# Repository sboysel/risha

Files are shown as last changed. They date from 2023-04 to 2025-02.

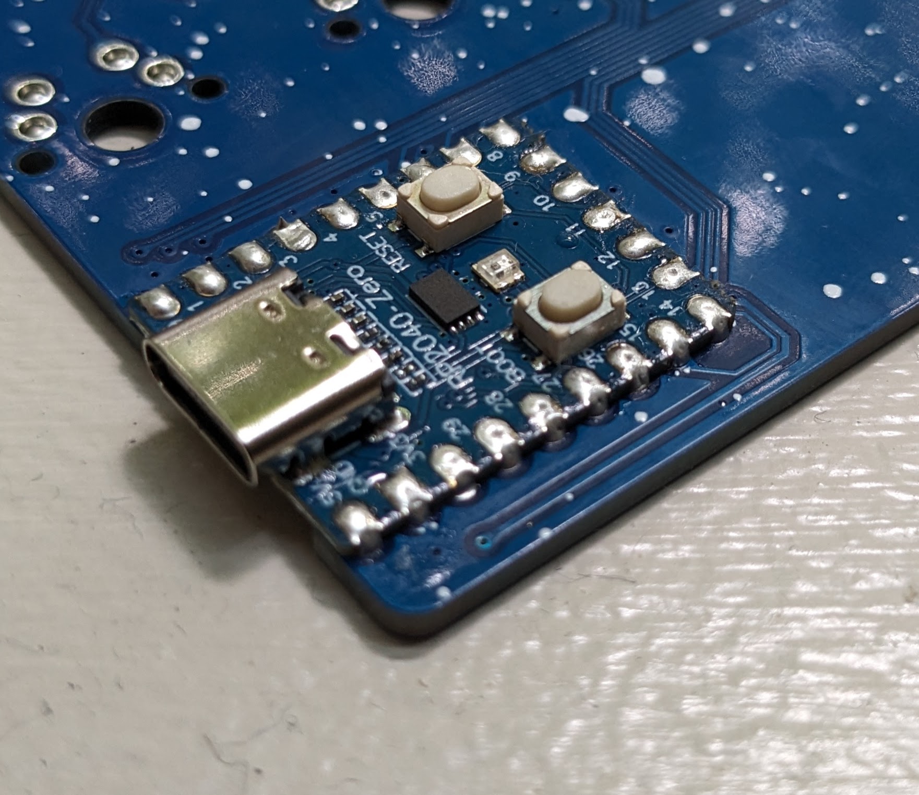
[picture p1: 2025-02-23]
img/rp2040zero-soldered.jpg

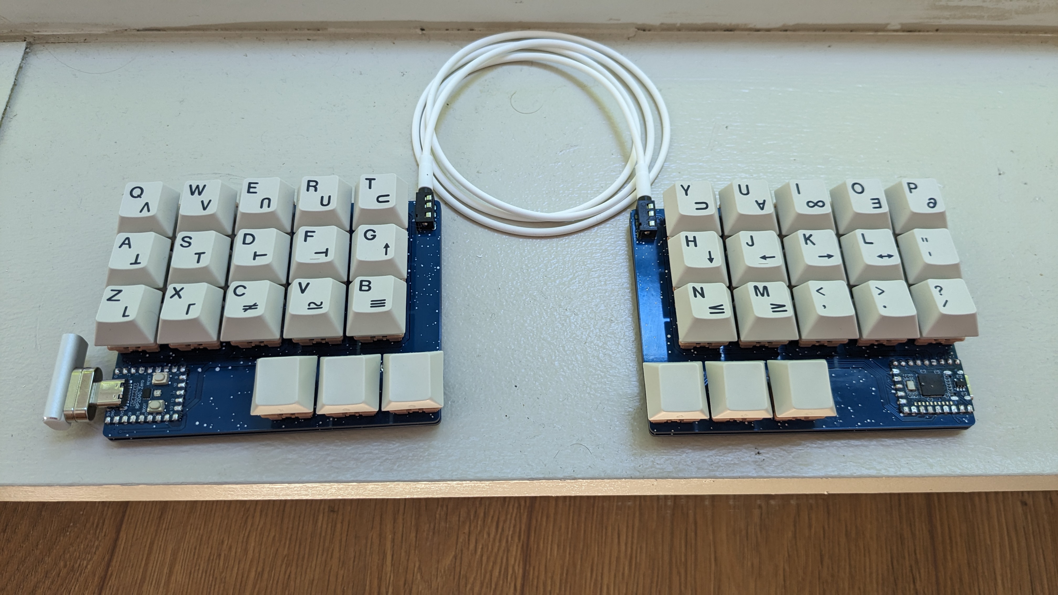
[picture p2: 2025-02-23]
img/full-build.jpg

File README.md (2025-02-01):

# Risha

Risha is an ultra-compact, wired split ortholinear keyboard featuring:

- **36 keys**
- **Diodeless, reversible PCB** (under 102mm x 102mm)
- **Waveshare RP2040-Zero** (cutout for flush mounting)
- **Rear-facing TRRS connection**

This design prioritizes affordability, simplicity, and ease of assembly. With a total cost of around **$40 AUD**, it's an excellent choice for a budget-friendly custom keyboard.

## Features

- **Fully split layout** with only 36 keys
- **No diodes required** for a simpler build process
- **Reversible PCB** (same PCB can be used for both halves)
- **Compact design** for travel and portability
- **RP2040-Zero powered**, enabling powerful firmware support with KMK
- **TRRS interconnection** between the halves

## Getting Started

To build your own Risha, check out the following guides:

- [Buying List](docs/buying_list.md) – Everything you need to order.
- [Build Instructions](docs/build_instructions.md) – Step-by-step assembly guide.
- [Flashing Guide](docs/flashing.md) – Installing KMK firmware.

## License
This project is open-source and freely available for personal and commercial use. Contributions are welcome!

---

### Additional Resources
- [KMK Firmware](https://github.com/KMKfw/kmk_firmware) – The firmware used for Risha
- [RP2040-Zero Docs](https://www.waveshare.com/wiki/RP2040-Zero) – Official documentation for the microcontroller

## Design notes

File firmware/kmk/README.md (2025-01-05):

# clyde kmk firmware

1. copy [CircuitPython](https://circuitpython.org/board/waveshare_rp2040_zero/) to RP2040 Zero
    ```sh
    wget https://downloads.circuitpython.org/bin/waveshare_rp2040_zero/en_US/adafruit-circuitpython-waveshare_rp2040_zero-en_US-8.2.4.uf2
    cp adafruit-circuitpython-waveshare_rp2040_zero-en_US-8.2.4.uf2 /run/media/sam/RPI-RP2/
    ```
2. Rename RP2040 Zeroes to end in `L` and `R`
    ```
    sudo umount /dev/sdb1
    sudo fatlabel /dev/sdb1 RISHAL
    ```
    Repeat for `RISHAR`
3. Copy `kmk_firmware/kmk` directory to each RP2040 Zero
    ```sh
    rm /run/media/sam/RISHAL/code.py
    cp -avr ~/repos/kmk_firmware/kmk /run/media/sam/RISHAL
    cp ~/repos/risha/firmware/kmk/kb.py /run/media/sam/RISHAL 
    cp ~/repos/risha/firmware/kmk/main.py /run/media/sam/RISHAL 
    ```
    Repeat for `RISHAR`
4. Copy board firmware to each RP2040 Zero. Use Piantor firmware as a starting point
    - https://raw.githubusercontent.com/cairnm/kmk_firmware/piantor/boards/beekeeb/piantor/kb.py
    - https://raw.githubusercontent.com/cairnm/kmk_firmware/piantor/boards/beekeeb/piantor/main.py 

## docs

- https://circuitpython.org/board/weact_studio_pico/
- http://kmkfw.io/docs/split_keyboards/

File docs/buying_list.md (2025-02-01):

# Buying List

Risha is an incredibly affordable custom keyboard, costing approximately **\$40 AUD** to build. Below are the essential and optional components required.

## Essential Parts

- **2 x Waveshare RP2040-Zero**
- **2 x TRRS jacks**
- **36 x Cherry MX-compatible switches**
- **A standard Cherry keycap set**

## Optional Parts

- **Rubber bumpers** for added grip and stability
- **Braided USB-C cable** for durability and aesthetics

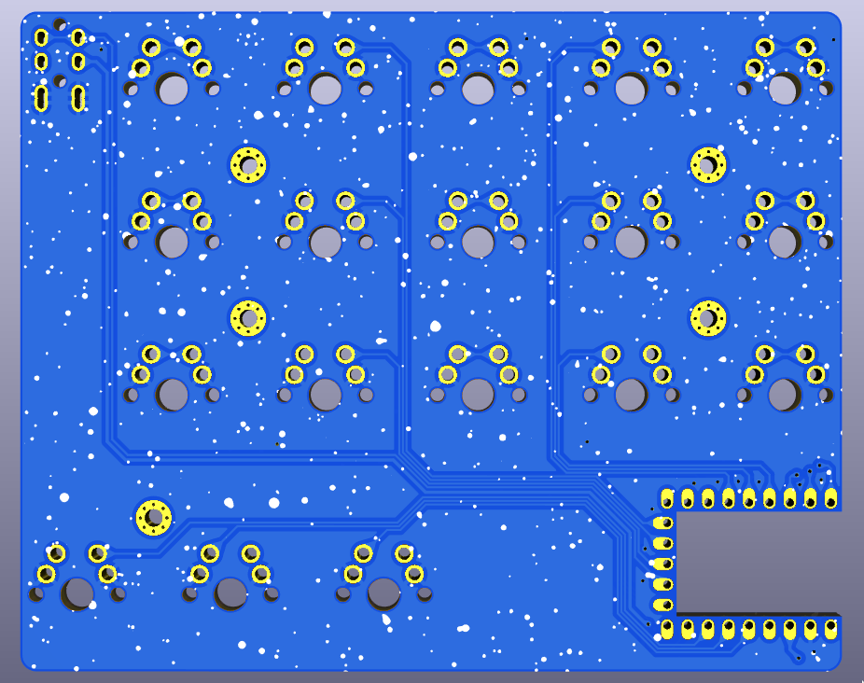
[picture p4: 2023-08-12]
img/risha-v0_3_0.png

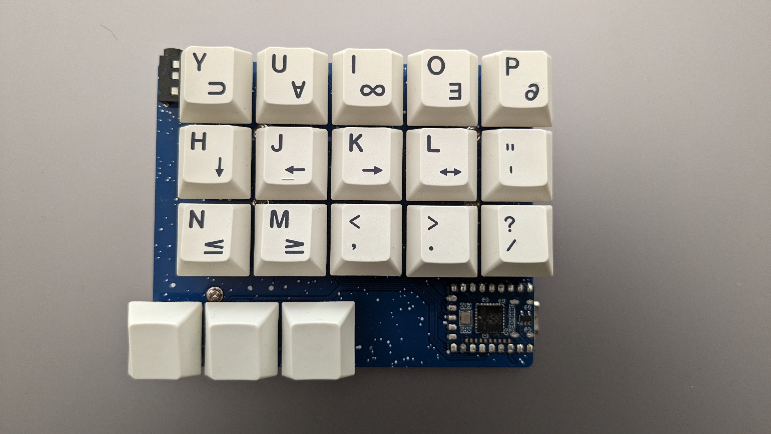
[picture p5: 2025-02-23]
img/rhs.jpg

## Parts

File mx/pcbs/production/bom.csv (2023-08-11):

Designator | Footprint | Quantity | Value | LCSC Part #
 | rp2040_zero_tht_pads | 1
S1, S10, S11, S12, S13, S14, S15, S16, S17, S18, S2, S3, S4, S5, S6, S7, S8, S9 | MX | 18
TRRS1 | TRRS-PJ-320A-dual | 1 | TRRS-PJ-320A-dual
_4, _5, _6 | MountingHole_2.2mm_M2_Pad_Via | 3

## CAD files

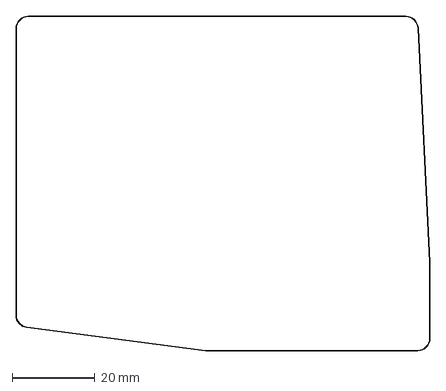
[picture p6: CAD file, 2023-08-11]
choc/outlines/risha-choc-bottom-plate.dxf
100.0 x 80.8 mm

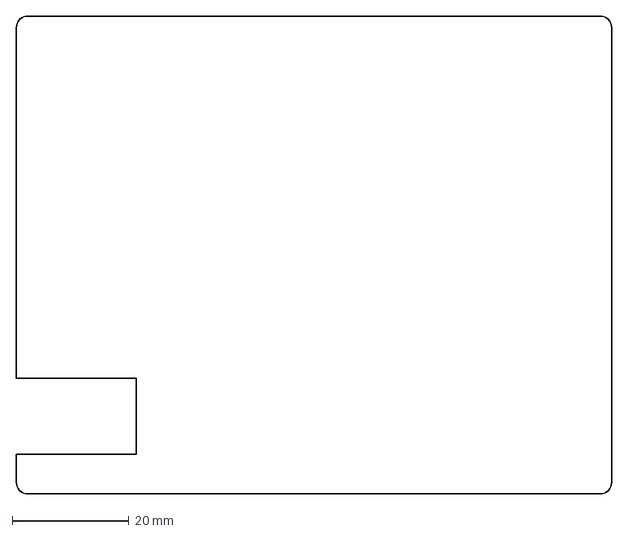
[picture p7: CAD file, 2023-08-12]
ergogen/outlines/risha.dxf
102.0 x 81.9 mm

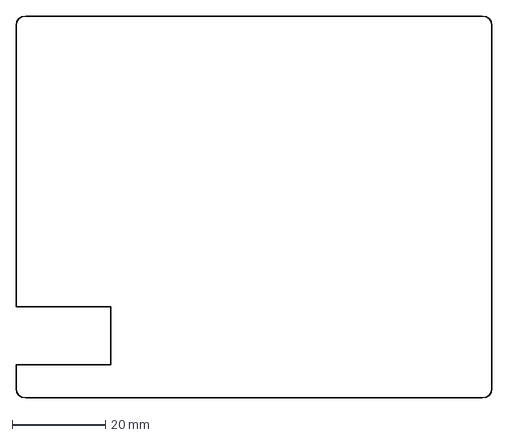
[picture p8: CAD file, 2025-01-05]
ergogen/output/outlines/risha.dxf
102.0 x 81.9 mm

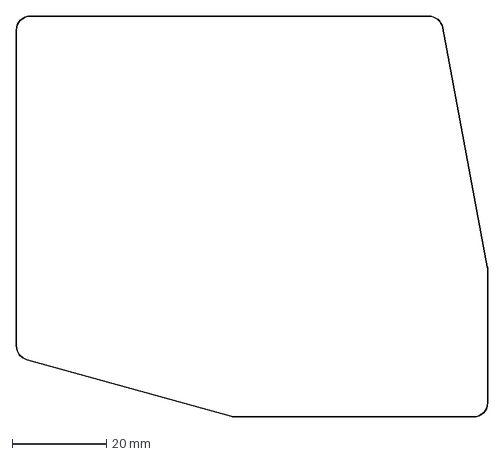
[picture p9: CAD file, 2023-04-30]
output/outlines/mosaic_bottom_plate.dxf
100.0 x 85.0 mm

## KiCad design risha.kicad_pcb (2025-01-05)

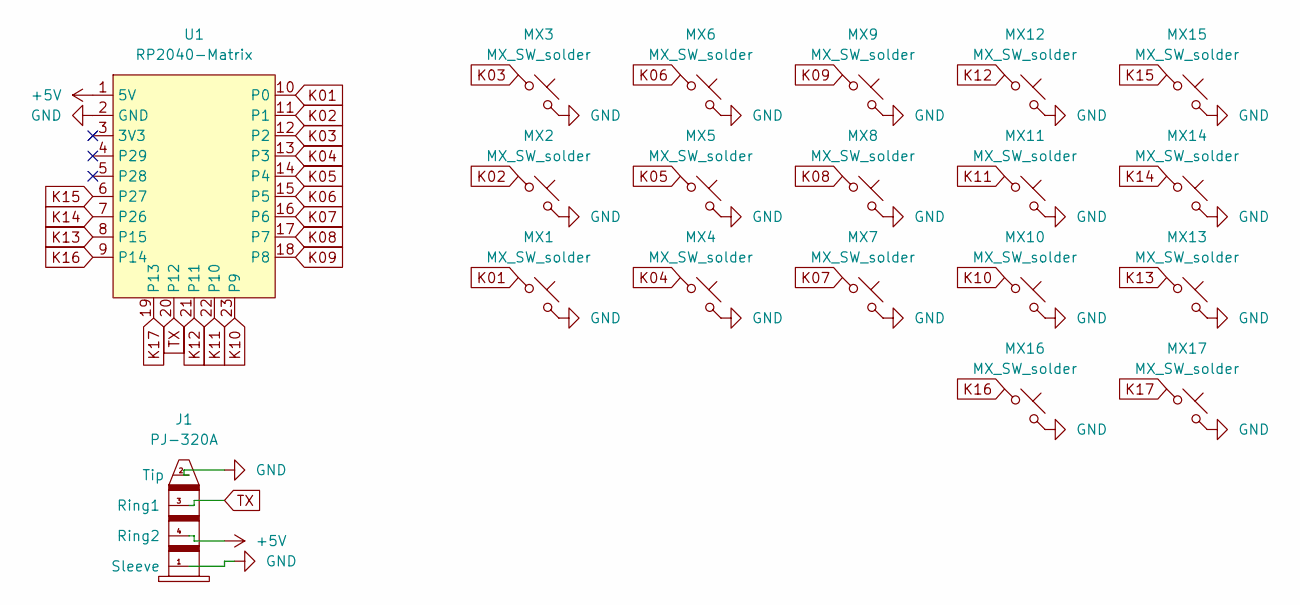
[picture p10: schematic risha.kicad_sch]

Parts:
J1: PJ-320A; PJ-320A_Reversible
MX1, MX2, MX3, MX4, MX5, MX6, MX7, MX8, MX9, MX10, MX11, MX12, MX13, MX14, MX15, MX16, MX17: MX_SW_solder; SW_MX_Reversible_1u
U1: RP2040-Matrix; RP2040-Matrix_AH

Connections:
+5V: J1.4 (Ring2), U1.1 (5V)
GND: J1.1 (Sleeve), J1.2 (Tip), MX1.2, MX2.2, MX3.2, MX4.2, MX5.2, MX6.2, MX7.2, MX8.2, MX9.2, MX10.2, MX11.2, MX12.2, MX13.2, MX14.2, MX15.2, MX16.2, MX17.2, U1.2 (GND)
K01: MX1.1, U1.10 (P0)
K02: MX2.1, U1.11 (P1)
K03: MX3.1, U1.12 (P2)
K04: MX4.1, U1.13 (P3)
K05: MX5.1, U1.14 (P4)
K06: MX6.1, U1.15 (P5)
K07: MX7.1, U1.16 (P6)
K08: MX8.1, U1.17 (P7)
K09: MX9.1, U1.18 (P8)
K10: MX10.1, U1.23 (P9)
K11: MX11.1, U1.22 (P10)
K12: MX12.1, U1.21 (P11)
K13: MX13.1, U1.8 (P15)
K14: MX14.1, U1.7 (P26)
K15: MX15.1, U1.6 (P27)
K16: MX16.1, U1.9 (P14)
K17: MX17.1, U1.19 (P13)
TX: J1.3 (Ring1), U1.20 (P12)

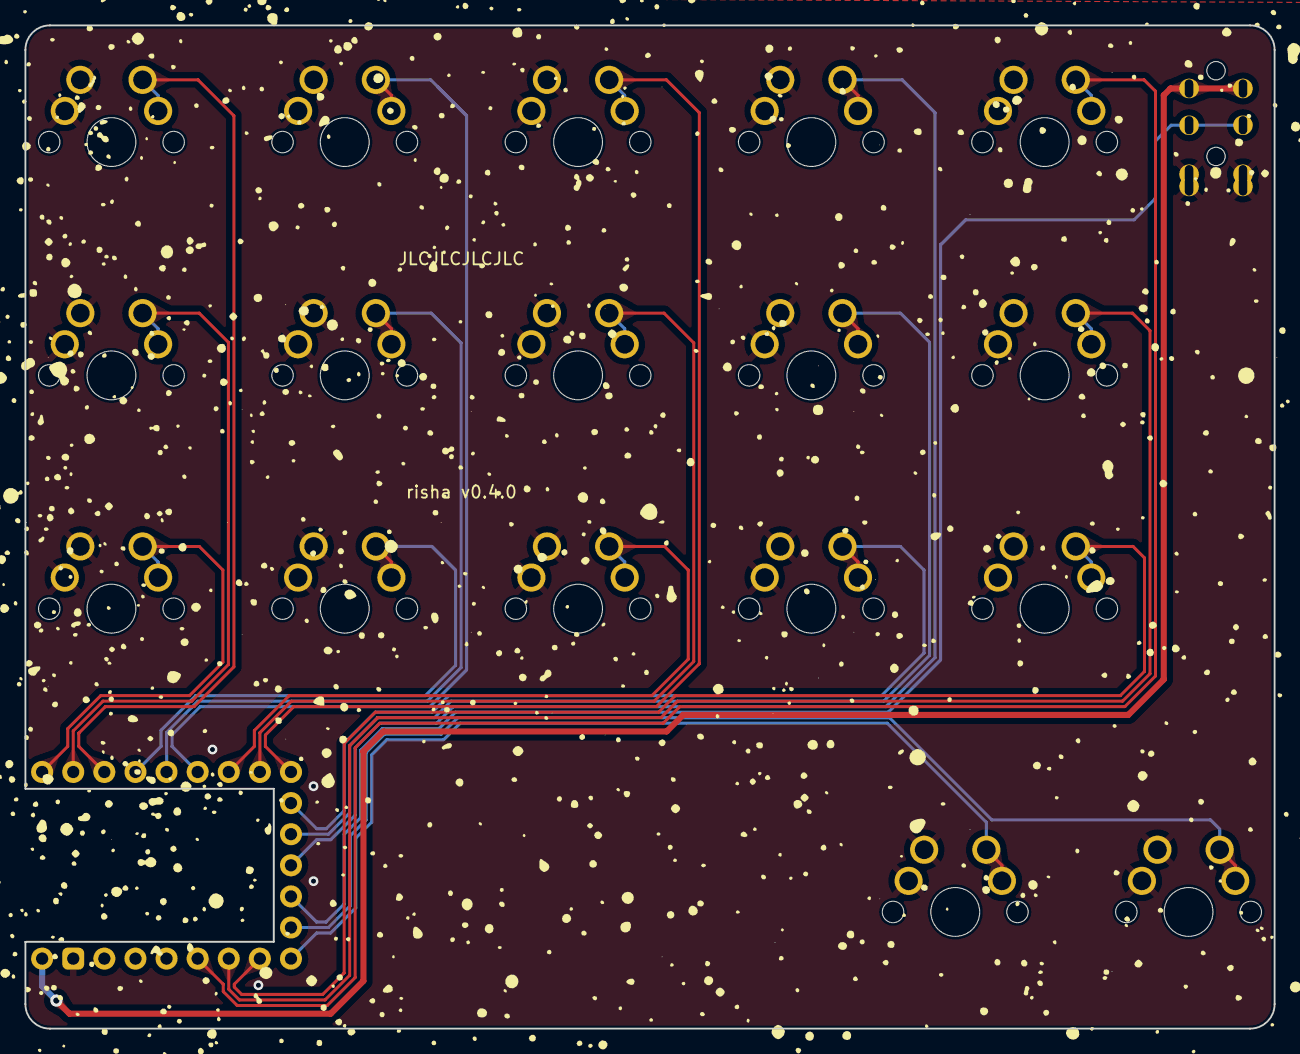
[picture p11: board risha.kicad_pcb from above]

Board: 2 copper layers, 102.0 x 81.9 mm, 19 parts (0 on the bottom side), 20 nets.

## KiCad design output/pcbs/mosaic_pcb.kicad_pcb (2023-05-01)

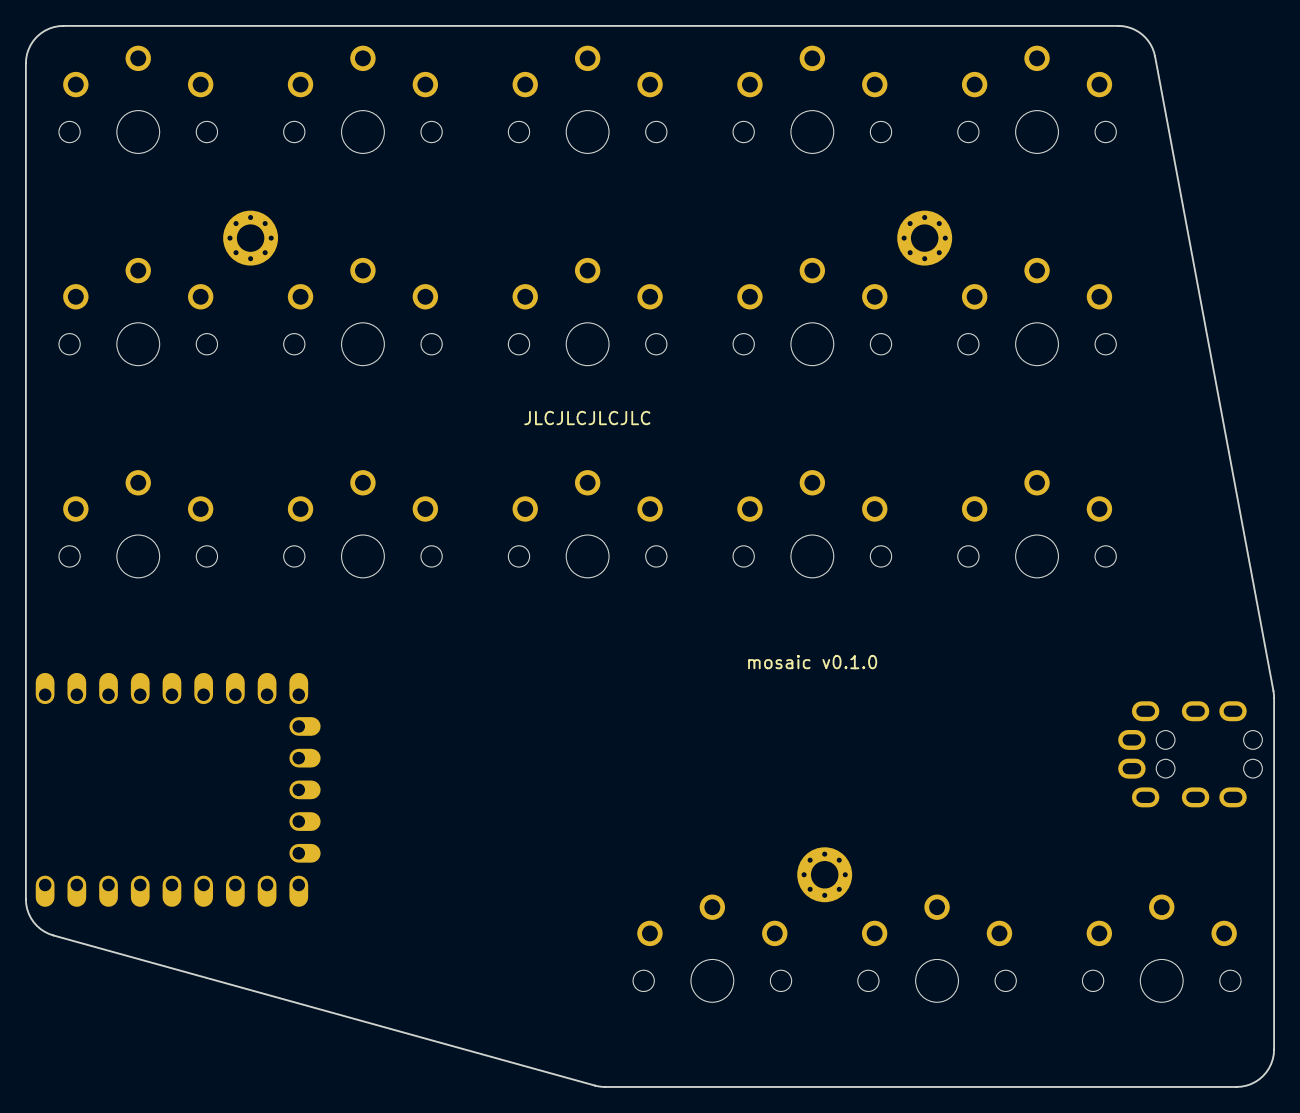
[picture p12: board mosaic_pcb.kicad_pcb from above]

Board: 2 copper layers, 100.0 x 85.0 mm, 22 parts (0 on the bottom side), 2 nets, no tracks yet.

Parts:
S1, S2, S3, S4, S5, S6, S7, S8, S9, S10, S11, S12, S13, S14, S15, S16, S17, S18: PG1350
TRRS1: TRRS-PJ-320A-dual
_2, _3, _4: MountingHole_2.2mm_M2_Pad_Via

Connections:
GND: S1.2, S2.2, S3.2, S4.2, S5.2, S6.2, S7.2, S8.2, S9.2, S10.2, S11.2, S12.2, S13.2, S14.2, S15.2, S16.2, S17.2, S18.2, TRRS1.2
GP8: TRRS1.3, TRRS1.4
GP9: TRRS1.3, TRRS1.4

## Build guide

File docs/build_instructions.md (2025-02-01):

# Build Instructions

Follow these steps to assemble your Risha keyboard:
1. Flash the 2 x **RP2040-Zero** Follow the [Flashing Guide](flashing.md) to install the firmware.

2. Take the **left-side PCB** and solder the **RP2040-Zero** with the buttons facing **up**.

3. Repeat the process for the **right-side PCB**, but flip the RP2040-Zero so that the controller sits on top.

4. Solder the **TRRS jacks** to both halves.

5. Solder the **switches** into place.

6. Attach the **keycaps** onto the switches.

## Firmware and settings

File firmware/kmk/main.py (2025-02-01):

import board

from kb import KMKKeyboard, isRight
keyboard = KMKKeyboard()

from kmk.keys import KC
from kmk.modules.split import Split, SplitSide, SplitType
from kmk.modules.layers import Layers; keyboard.modules.append(Layers())
from kmk.modules.holdtap import HoldTap; keyboard.modules.append(HoldTap())
from kmk.modules.mouse_keys import MouseKeys; keyboard.modules.append(MouseKeys())
from kmk.modules.power import Power; keyboard.modules.append(Power())
from kmk.modules.tapdance import TapDance; keyboard.modules.append(TapDance())
from kmk.extensions.media_keys import MediaKeys; keyboard.extensions.append(MediaKeys())
from kmk.modules.capsword import CapsWord; keyboard.modules.append(CapsWord())

keyboard.tap_time = 100

split_side = SplitSide.RIGHT if isRight else SplitSide.LEFT

split = Split(
    split_side=split_side,
    split_type=SplitType.UART,
    split_flip=True,
    split_target_left=SplitSide.LEFT,
    # uart_flip=True,
    data_pin=board.GP12,
    # data_pin2=board.GP0,
    use_pio=True,
)
keyboard.modules.append(split)


# === layer tap ---------------------------------------------------------------
# NAV (layer 1)
LT_TAB = KC.LT(1, KC.TAB, prefer_hold=True, tap_interrupted=False, tap_time=200)
LT_SPC = KC.LT(1, KC.SPC, prefer_hold=True, tap_interrupted=False, tap_time=200)
# NUM (layer 2)
LT_BSPC = KC.LT(2, KC.BSPC, prefer_hold=True, tap_interrupted=False, tap_time=200)
# SYM (layer 3)
LT_ENT = KC.LT(3, KC.ENT, prefer_hold=True, tap_interrupted=False, tap_time=200)
# FUN (layer 4)
LT_DEL = KC.LT(4, KC.DEL, prefer_hold=True, tap_interrupted=False, tap_time=200)
# MEDIA (layer 5)
LT_ESC = KC.LT(5, KC.ESC, prefer_hold=True, tap_interrupted=False, tap_time=200)

# === home row mods ------------------------------------------------------------
MT_A = KC.HT(KC.A, KC.LGUI, prefer_hold=False, tap_interrupted=True, tap_time=200)
MT_S = KC.HT(KC.S, KC.LALT, prefer_hold=False, tap_interrupted=True, tap_time=200)
MT_D = KC.HT(KC.D, KC.LCTL, prefer_hold=False, tap_interrupted=True, tap_time=200)
MT_F = KC.HT(KC.F, KC.LSFT, prefer_hold=False, tap_interrupted=True, tap_time=200)

MT_J = KC.HT(KC.J, KC.LSFT, prefer_hold=False, tap_interrupted=True, tap_time=200)
MT_K = KC.HT(KC.K, KC.LCTL, prefer_hold=False, tap_interrupted=True, tap_time=200)
MT_L = KC.HT(KC.L, KC.LALT, prefer_hold=False, tap_interrupted=True, tap_time=200)
MT_QUOT = KC.HT(KC.QUOT, KC.LGUI, prefer_hold=False, tap_interrupted=True, tap_time=200)

# === keymap -------------------------------------------------------------------
keyboard.keymap = [
    # QWERTY
    [
        KC.Q,    KC.W,    KC.E,    KC.R,    KC.T,       KC.Y,   KC.U,    KC.I,    KC.O,    KC.P,
        MT_A,    MT_S,    MT_D,    MT_F,    KC.G,       KC.H,   MT_J,    MT_K,    MT_L,    MT_QUOT,
        KC.Z,    KC.X,    KC.C,    KC.V,    KC.B,       KC.N,   KC.M,    KC.COMM, KC.DOT,  KC.SLSH,
                          LT_ESC,  LT_SPC,  LT_TAB,     LT_ENT, LT_BSPC, LT_DEL,
    ],                  
    #                     MEDIA             NAV         NUM     SYM      FUN
    # NAV
    [
        KC.NO,   KC.NO,   KC.NO,   KC.NO,   KC.NO,      KC.NO,  KC.NO,   KC.NO,   KC.NO,   KC.NO,
        KC.LGUI, KC.LALT, KC.LCTL, KC.LSFT, KC.NO,      KC.ESC, KC.LEFT, KC.DOWN, KC.UP,   KC.RGHT,
        KC.NO,   KC.RALT, KC.NO,   KC.NO,   KC.NO,      KC.INS, KC.HOME, KC.PGDN, KC.PGUP, KC.END,
                          KC.NO,   KC.NO,   KC.NO,      KC.ENT, KC.BSPC, KC.DEL, 
    ],
    # NUM
    [
        KC.LBRC, KC.N7,   KC.N8,   KC.N9,   KC.RBRC,    KC.NO,  KC.NO,   KC.NO,   KC.NO,   KC.NO,
        KC.SCLN, KC.N4,   KC.N5,   KC.N6,   KC.EQL,     KC.NO,  KC.LSFT, KC.LCTL, KC.LALT, KC.LGUI,
        KC.GRV,  KC.N1,   KC.N2,   KC.N3,   KC.BSLS,    KC.NO,  KC.NO,   KC.NO,   KC.RALT, KC.NO,
                          KC.DOT,  KC.N0,   KC.MINS,    KC.NO,  KC.NO,   KC.NO,
    ],
    # SYM
    [
        KC.LCBR, KC.AMPR, KC.ASTR, KC.LPRN, KC.RCBR,    KC.NO,  KC.NO,   KC.NO,   KC.NO,   KC.NO,
        KC.COLN, KC.DLR,  KC.PERC, KC.CIRC, KC.PLUS,    KC.NO,  KC.LSFT, KC.LCTL, KC.LALT, KC.LGUI,
        KC.TILD, KC.EXLM, KC.AT,   KC.HASH, KC.PIPE,    KC.NO,  KC.NO,   KC.NO,   KC.RALT, KC.NO,
                          KC.LPRN, KC.RPRN, KC.UNDS,    KC.NO,  KC.NO,   KC.NO,
    ],
    # FUN
    [
        KC.F12,  KC.F7,   KC.F8,   KC.F9,   KC.PSCR,    KC.NO,  KC.NO,   KC.NO,   KC.NO,   KC.NO,
        KC.F11,  KC.F4,   KC.F5,   KC.F6,   KC.SLCK,    KC.NO,  KC.LSFT, KC.LCTL, KC.LALT, KC.LGUI,
        KC.F10,  KC.F1,   KC.F2,   KC.F3,   KC.PAUS,    KC.NO,  KC.NO,   KC.NO,   KC.RALT, KC.NO,
                          KC.APP,  KC.SPC,  KC.TAB,     KC.NO,  KC.NO,   KC.NO,
    ],
    # MEDIA
    [
        KC.NO,   KC.NO,   KC.NO,   KC.NO,   KC.NO,      KC.NO,     KC.NO,   KC.NO,   KC.NO,   KC.NO,
        KC.LGUI, KC.LALT, KC.LCTL, KC.LSFT, KC.NO,      KC.PS_TOG, KC.MPRV, KC.VOLD, KC.VOLU, KC.MNXT,
        KC.NO,   KC.RALT, KC.NO,   KC.NO,   KC.NO,      KC.HID,    KC.NO,   KC.NO,   KC.NO,   KC.NO,
                          KC.NO,   KC.NO,   KC.NO,      KC.MSTP,   KC.MPLY, KC.MUTE,
    ],
]

layer_names_list = [
    'QWERTY', 'NAV', 'NUM', 'SYM', 'FUN', 'MEDIA',
]

if __name__ == '__main__':
    keyboard.go()

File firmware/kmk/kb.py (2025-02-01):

import board

from storage import getmount

from kmk.kmk_keyboard import KMKKeyboard as _KMKKeyboard
from kmk.scanners.keypad import KeysScanner

# set side based on drive names
name = str(getmount('/').label)
isRight = True if name.endswith('R') else False

# GP0: matrix_pinky_bottom
# GP1: matrix_pinky_home
# GP2: matrix_pinky_top
# GP3: matrix_ring_bottom
# GP4: matrix_ring_home
# GP5: matrix_ring_top
# GP6: matrix_middle_bottom
# GP7: matrix_middle_home
# GP8: matrix_middle_top
# GP9: matrix_index_top
# GP10: matrix_index_home
# GP11: matrix_index_bottom
# GP13: matrix_inner_bottom
# GP14: matrix_inner_home
# GP15: matrix_inner_top
# GP26: thumbfan_far_home
# GP27: thumbfan_middle_home
# GP28: thumbfan_near_home


# GPIO to key mapping, Left
_KEY_CFG_LEFT = [
    board.GP2, board.GP5, board.GP8,  board.GP9,  board.GP15,
    board.GP1, board.GP4, board.GP7,  board.GP10, board.GP14,
    board.GP0, board.GP3, board.GP6,  board.GP11, board.GP13,
                          board.GP28, board.GP27, board.GP26 
]

# GPIO to key mapping, Left
_KEY_CFG_RIGHT = [
    board.GP15, board.GP9,  board.GP8, board.GP5, board.GP2,
    board.GP14, board.GP10, board.GP7, board.GP4, board.GP1,
    board.GP13, board.GP11, board.GP6, board.GP3, board.GP0,
    board.GP26, board.GP27, board.GP28
]

class KMKKeyboard(_KMKKeyboard):
    def __init__(self):
        # create and register the scanner
        self.matrix = KeysScanner(
            pins = _KEY_CFG_RIGHT if isRight == True else _KEY_CFG_LEFT,
            value_when_pressed = false
        )

    # flake8: noqa
    # fmt: off
    coord_mapping = [
         0,  1,  2,  3,  4,   18, 19, 20, 21, 22,
         5,  6,  7,  8,  9,   23, 24, 25, 26, 27,
        10, 11, 12, 13, 14,   28, 29, 30, 31, 32,
                15, 16, 17,   33, 34, 35
    ]

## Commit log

2023-04-30 mosaic v0.0.1 (#1)
    * rp2040 zero,diodeless, hotswap
    [mosaic-B_Cu.gbl, mosaic-B_Mask.gbs, mosaic-B_Paste.gbp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]
2023-05-01 v0.1.0: cleaner routing for split comm traces
    [mosaic-B_Cu.gbl, mosaic-B_Mask.gbs, mosaic-B_Paste.gbp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]
2023-08-11 rename; choc and MX versions
    [mosaic-B_Cu.gbl, mosaic-B_Mask.gbs, mosaic-B_Paste.gbp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]
2023-08-11 tweak outline for MX version
    [risha-mx-bottom-plate.dxf, risha-mx.kicad_pcb]
2023-08-11 adding image for silkscreen
2023-08-11 adding version and JLC text
    [risha-choc.kicad_pcb, risha-mx.kicad_pcb]
2023-08-11 drop mx thumb cluster a little lower
    [risha-choc.kicad_pcb, risha-mx-bottom-plate.dxf, risha-mx.kicad_pcb]
2023-08-11 outline tweaks for ergonomics
    [risha-choc-bottom-plate.dxf, risha-choc.kicad_pcb, risha-mx-bottom-plate.dxf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]
2023-08-11 hacky sub 100mm^2 idea for rear-facing trrs
    [mcu-cutout.dxf, risha-choc-bottom-plate.dxf, risha-choc.kicad_pcb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]
2023-08-11 risha v0.2.0
    [bom.csv, designators.csv, positions.csv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]
2023-08-11 trying new choc outline
    [risha-choc-bottom-plate.dxf, risha-choc.kicad_pcb]
2023-08-12 v0.3.0 (#3)
    * v0.3.0 prototypes ordered
    [bom.csv, designators.csv, mcu-cutout.dxf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]
2025-01-05 finish routing
    [risha.dxf, risha.kicad_pcb, risha.kicad_sch]
